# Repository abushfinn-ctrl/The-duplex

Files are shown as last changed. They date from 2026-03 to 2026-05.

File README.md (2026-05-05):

# The-duplex
A wireless split keyboard with 42 keys, made in a 3d printed case. Designed and built for HackClub and improved typing erogonomics. I got a new Macbook lately and my old keyboard was on it's last few breaths, so I decided to make a new keyboard that is also ergonomic. You can use the PCB files to order the PCB from Jlcpcb or your preffered PCB manufacturer. The bill of materials is also provided, look at aliexpress but if the parts are available locally for cheaper then obviously that would work aswell. I printed the case in Clay colour Matte PLA with a layer height of 0.2mm on my Prusa Mk3s+.
# Finished!
I finished the project and i've been waiting to be a little bit more free with school to do this journal. I modified the case because it was going to be too thick with the battery inside so I decided to put the battery on top next to the keys. Everything went pretty smoothly I used some heat inserts and double sided tape for the battery. Overall I like it, it looks cool but I'm not sure I really enjoy typing on it. It's not quite the right positions for the keys and it's just off so I can only get 45WPM vs my normal 110WPM. But i learnt a lot and had fun! I added some leather on the bottom so it grips a little better too.



# The Schematic
The schematic is split into a left and right side with the root sheet having the mousebites.
Here is the left side. 

And here is the right side. Exactly the same.

 We can achieve this by using hierarchical sheets. 
 
To make hierarchical sheeting you can click this button on the side bar or the keyboard button S.
Once setup your heirarchy should look like this.


# The PCB
The PCB is fairly simple. Import a template into kicad to use as a layout tool on where to place the switches. I used ergogen (https://ergogen.xyz/new) to edit a layout and then important that into Kicad as an image to get roughly lined up. Here is my PCB at the very end after routing and drawing my edge cuts.

Don't forget to add some customisation like your name!

# The Case 
I designed the case in Autodesk Fusion, there we're 100% some issues but nothing a bit of time and youtube videos can't fix. I designed the top and then bottom then mirrored and copied them for the other side.


# BOM
| Item | Description | Quantity | Unit Price (CAD$) | Total Price (CAD$) | Unit Price (USD$) | Total Price (USD$) | URL | Running total (CAD$ with tax) | Running total (USD$ with tax) |
| --- | --- | --- | --- | --- | --- | --- | --- | --- | --- |
| 102050 1000mAh LiPO Battery | 20mm\*50mm\*10mm 3.7v Lithium battery. 2Pack | 1 | $12.38 | $12.38 | $8.90 | $8.90 | [Battery](https://www.aliexpress.com/item/1005006394926759.html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) | 12.38$ | 8.90$ |
| Gateron Switches 50 Pack | 50 Gateron Auburn Switches | 1 | $22.71 | $22.71 | $16.33 | $16.33 | [Switches](https://www.aliexpress.com/item/1005006091988869.html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) | 35.09$ | 25.23$ |
| XIAO nRF52840 | XIAO 2 pack microcontroller | 1 | $47.72 | $47.72 | $34.31 | $34.31 | [XIAO](https://www.aliexpress.com/item/1005009937098547.html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) | 82.81$ | 59.54$ |
| Gateron Hotswap Sockets | 70pack of Gateron hotswap sockets | 1 | $22.64 | $22.64 | $16.28 | $16.28 | [Hotswap Sockets](https://www.aliexpress.com/item/1005007267551458.html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) | 105.45$ | 75.81$ |
| PCB | 5 PCB's ordered from JLCPCB | 1 | $58.41 | $58.41 | $41.99 | $41.99 | N/A | 163.86$ | 117.81$ |
| 1N5189 Diodes | 100 pieces | 1 | $3.05 | $3.05 | $2.19 | $2.19 | [DIODE](https://www.aliexpress.com/item/1005004617332808.html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) | 166.91$ | 120.00$ |
| Keycaps | Already have | | | | | | | | |

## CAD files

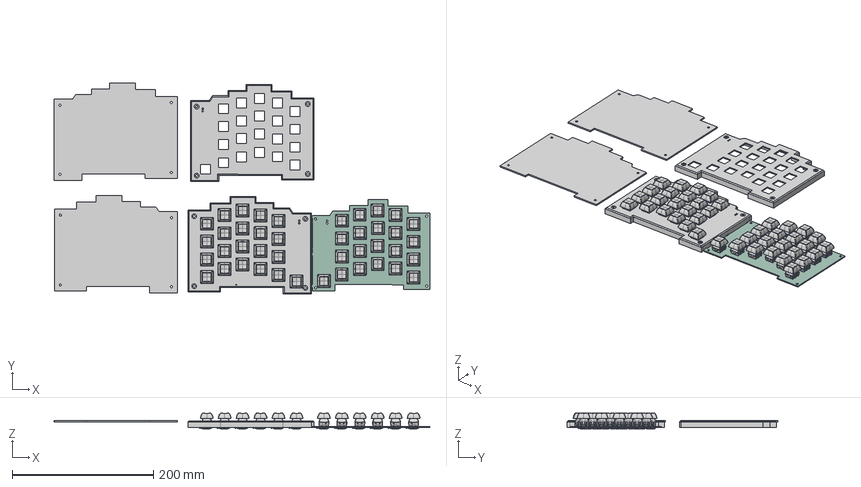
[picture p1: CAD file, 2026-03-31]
CAD/TheDuplex.step
532.1 x 298.5 x 22.0 mm
Contact x 84
DSA_Keycap_CherryMX x 42
splitkbd 1.3.1 x 42
D_SOD-123 x 42
R_0805_2012Metric x 4
splitkbd_PCB

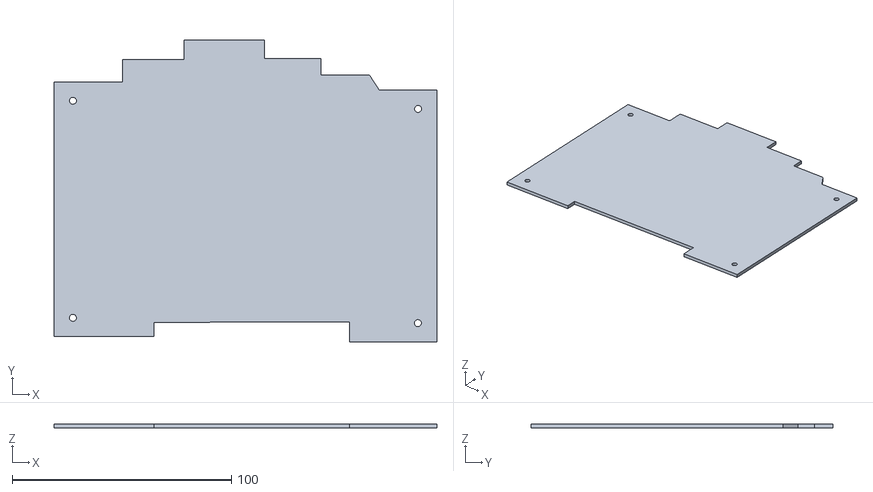
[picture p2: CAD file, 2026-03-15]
CAD/leftbottom.stl
174.6 x 137.7 x 2.00

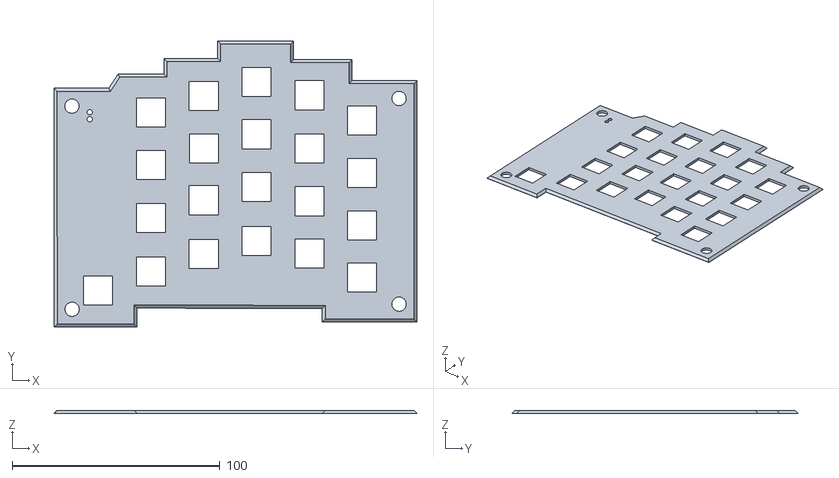
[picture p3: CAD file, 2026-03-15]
CAD/righttop.stl
174.6 x 137.7 x 1.60

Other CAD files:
CAD/rightbottom.stl
CAD/lefttop.stl
CAD/TheDuplex.f3z

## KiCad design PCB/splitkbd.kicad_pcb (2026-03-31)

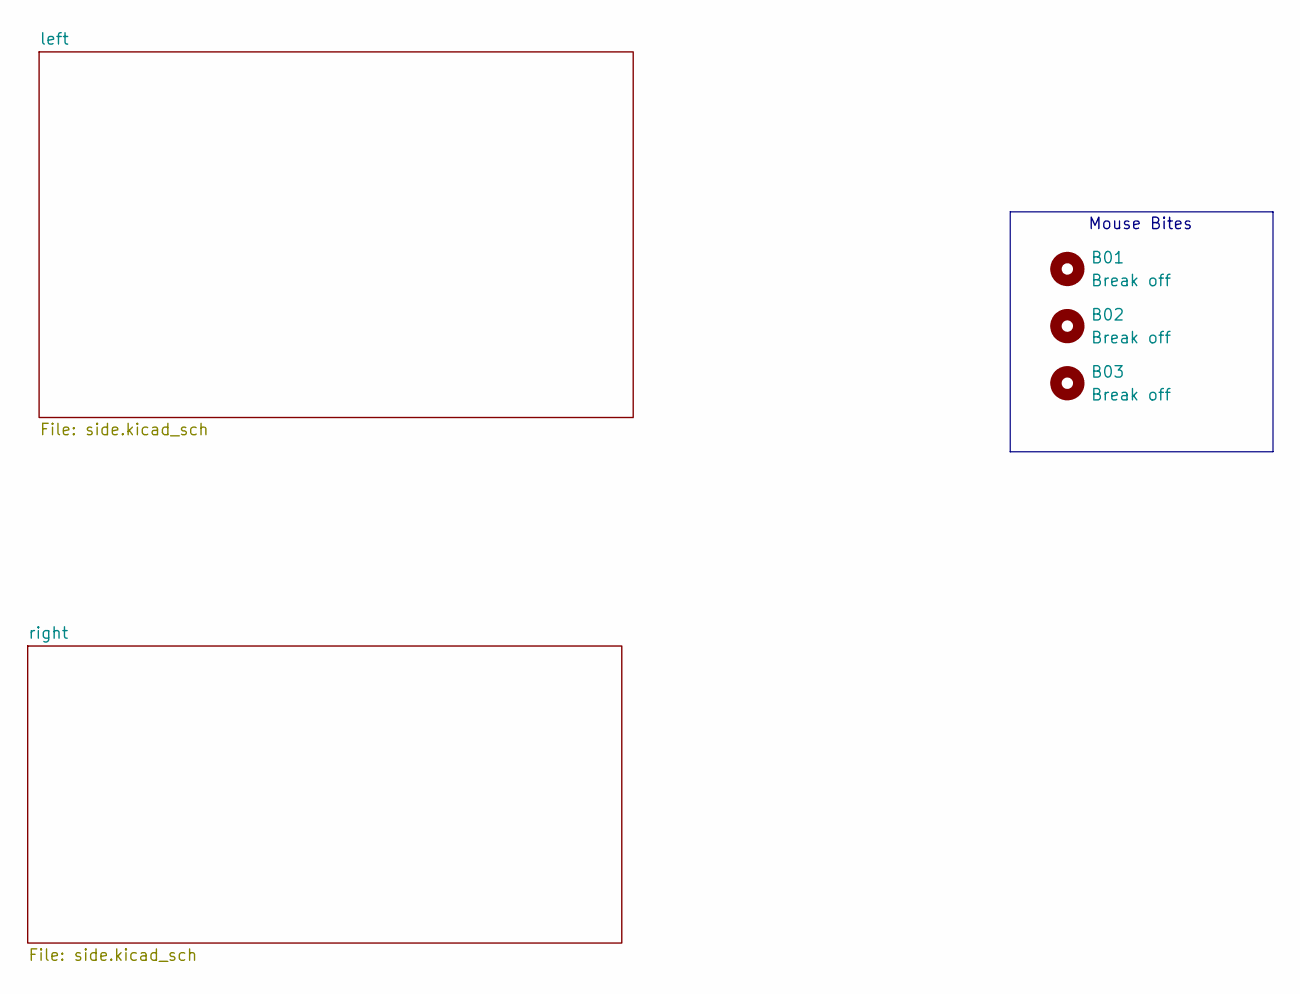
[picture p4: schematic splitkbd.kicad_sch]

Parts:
B01, B02, B03: Break off; mouse-bite-5mm-slot

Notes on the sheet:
Mouse Bites

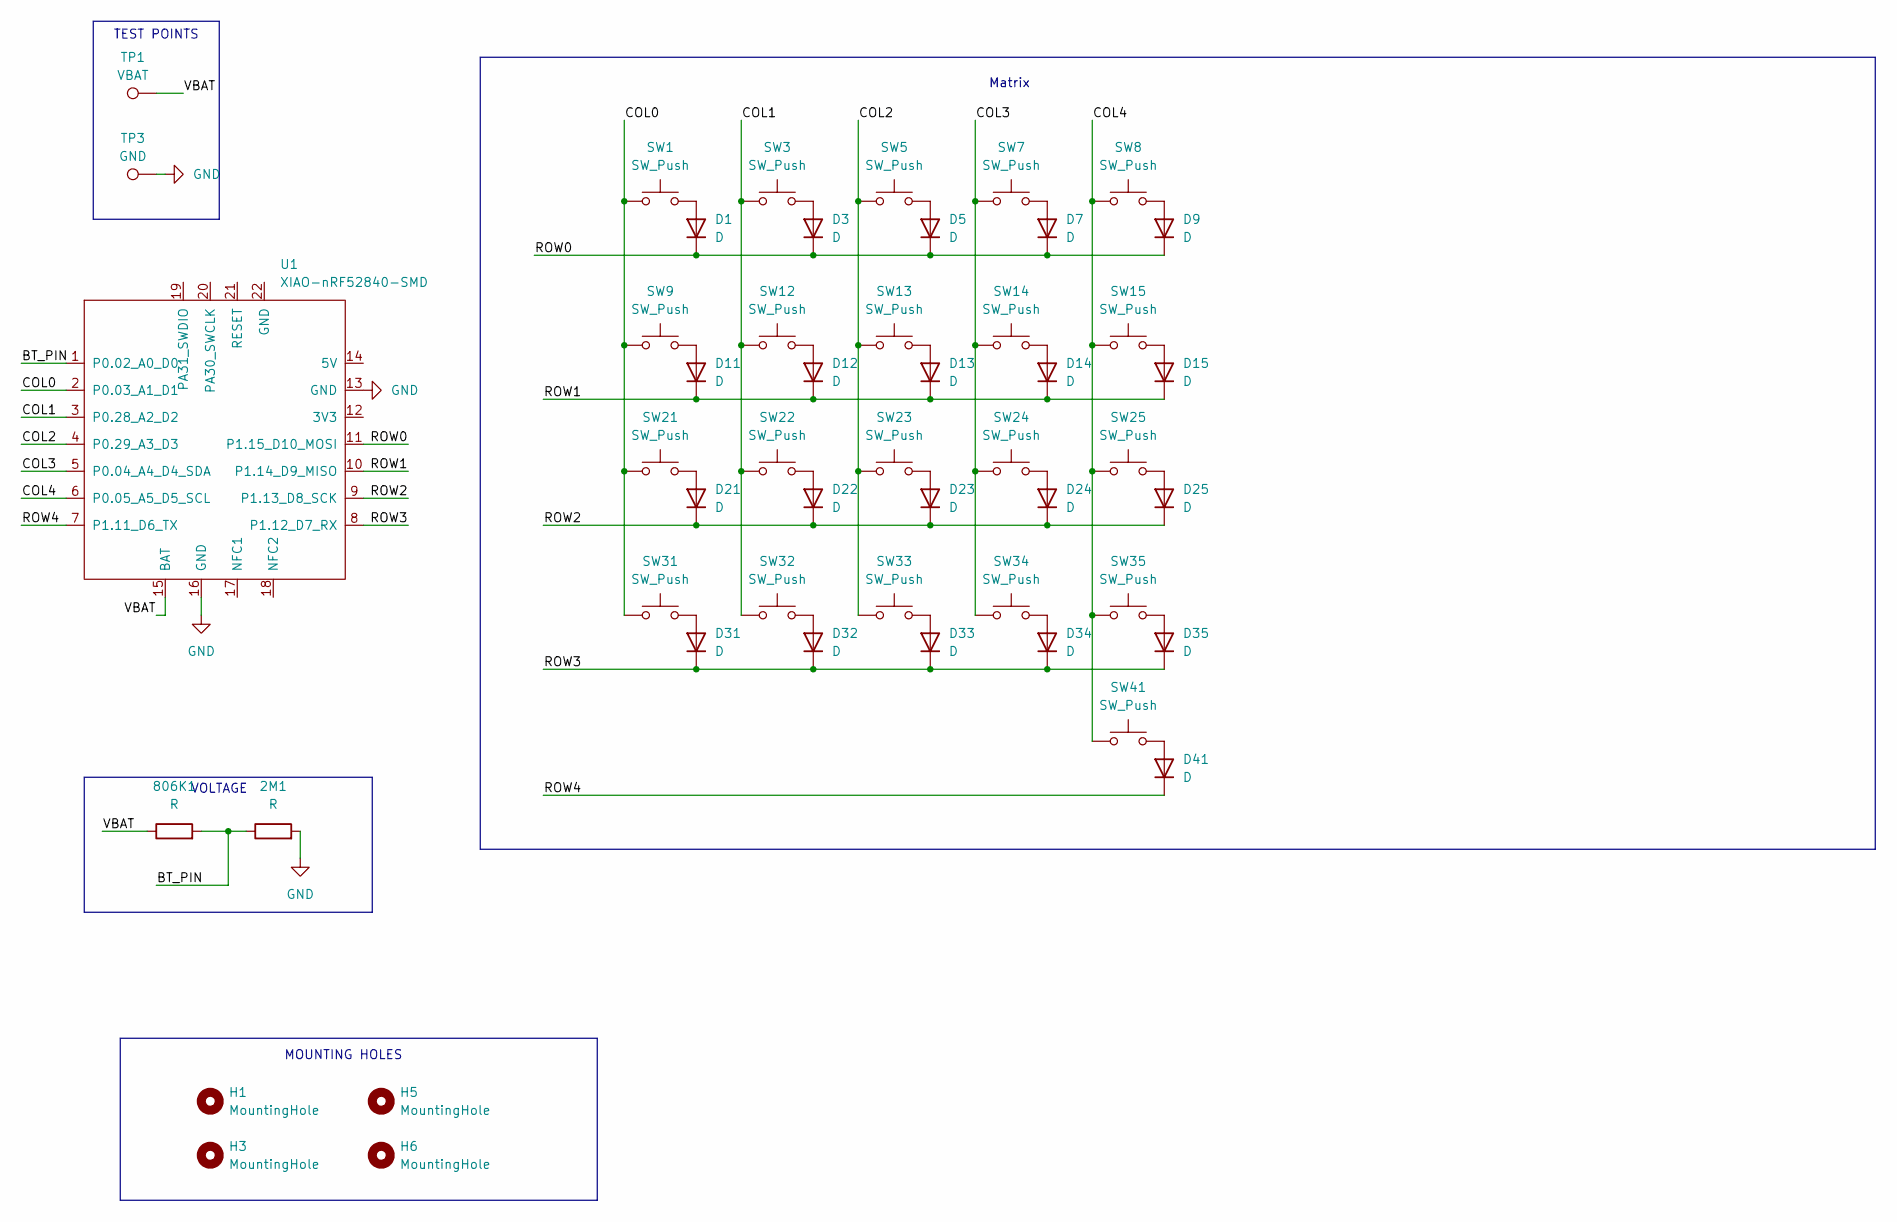
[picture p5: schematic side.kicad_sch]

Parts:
2M1, 806K1: R; R_0805_2012Metric
D1, D3, D5, D7, D9, D11, D12, D13, D14, D15, D21, D22, D23, D24, D25, D31, D32, D33, D34, D35, D41: D; D_SOD-123
H1, H3, H5, H6: MountingHole; MountingHole_3.2mm_M3
SW1, SW3, SW5, SW7, SW8, SW9, SW12, SW13, SW14, SW15, SW21, SW22, SW23, SW24, SW25, SW31, SW32, SW33, SW34, SW35, SW41: SW_Push; SW_MX_HS_CPG151101S11_1.25u
TP1: VBAT; TestPoint_Pad_2.0x2.0mm
TP3: GND; TestPoint_Pad_2.0x2.0mm
U1: XIAO-nRF52840-SMD; modified-XIAO-nRF52840-SMD

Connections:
/left/BT_PIN: 2M1.1, 806K1.2, U1.1 (P0.02_A0_D0)
/left/COL0: SW1.1, SW9.1, SW21.1, SW31.1, U1.2 (P0.03_A1_D1)
/left/COL1: SW3.1, SW12.1, SW22.1, SW32.1, U1.3 (P0.28_A2_D2)
/left/COL2: SW5.1, SW13.1, SW23.1, SW33.1, U1.4 (P0.29_A3_D3)
/left/COL3: SW7.1, SW14.1, SW24.1, SW34.1, U1.5 (P0.04_A4_D4_SDA)
/left/COL4: SW8.1, SW15.1, SW25.1, SW35.1, SW41.1, U1.6 (P0.05_A5_D5_SCL)
/left/ROW0: D1.1 (K), D3.1 (K), D5.1 (K), D7.1 (K), D9.1 (K), U1.11 (P1.15_D10_MOSI)
/left/ROW1: D11.1 (K), D12.1 (K), D13.1 (K), D14.1 (K), D15.1 (K), U1.10 (P1.14_D9_MISO)
/left/ROW2: D21.1 (K), D22.1 (K), D23.1 (K), D24.1 (K), D25.1 (K), U1.9 (P1.13_D8_SCK)
/left/ROW3: D31.1 (K), D32.1 (K), D33.1 (K), D34.1 (K), D35.1 (K), U1.8 (P1.12_D7_RX)
/left/ROW4: D41.1 (K), U1.7 (P1.11_D6_TX)
/left/VBAT: 806K1.1, TP1.1, U1.15 (BAT)
GND: 2M1.2, TP3.1, U1.13 (GND), U1.16 (GND); also elsewhere on the board
unnamed: D1.2 (A), SW1.2
unnamed: D3.2 (A), SW3.2
unnamed: D5.2 (A), SW5.2
unnamed: D7.2 (A), SW7.2
unnamed: D9.2 (A), SW8.2
unnamed: D11.2 (A), SW9.2
unnamed: D12.2 (A), SW12.2
unnamed: D13.2 (A), SW13.2
unnamed: D14.2 (A), SW14.2
unnamed: D15.2 (A), SW15.2
unnamed: D21.2 (A), SW21.2
unnamed: D22.2 (A), SW22.2
unnamed: D23.2 (A), SW23.2
unnamed: D24.2 (A), SW24.2
unnamed: D25.2 (A), SW25.2
unnamed: D31.2 (A), SW31.2
unnamed: D32.2 (A), SW32.2
unnamed: D33.2 (A), SW33.2
unnamed: D34.2 (A), SW34.2
unnamed: D35.2 (A), SW35.2
unnamed: D41.2 (A), SW41.2

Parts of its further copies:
D2, D4, D6, D8, D10, D16, D17, D18, D19, D20, D26, D27, D28, D29, D30, D36, D37, D38, D39, D40, D42: D; D_SOD-123
H2, H4, H7, H8: MountingHole; MountingHole_3.2mm_M3
R2, R4: R; R_0805_2012Metric
SW2, SW4, SW6, SW10, SW11, SW16, SW17, SW18, SW19, SW20, SW26, SW27, SW28, SW29, SW30, SW36, SW37, SW38, SW39, SW40, SW42: SW_Push; SW_MX_HS_CPG151101S11_1.25u
TP2: VBAT; TestPoint_Pad_2.0x2.0mm
TP4: GND; TestPoint_Pad_2.0x2.0mm
U2: XIAO-nRF52840-SMD; modified-XIAO-nRF52840-SMD

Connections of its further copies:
/right/BT_PIN: R2.2, R4.1, U2.1 (P0.02_A0_D0)
/right/COL0: SW2.1, SW16.1, SW26.1, SW36.1, U2.2 (P0.03_A1_D1)
/right/COL1: SW4.1, SW17.1, SW27.1, SW37.1, U2.3 (P0.28_A2_D2)
/right/COL2: SW6.1, SW18.1, SW28.1, SW38.1, U2.4 (P0.29_A3_D3)
/right/COL3: SW10.1, SW19.1, SW29.1, SW39.1, U2.5 (P0.04_A4_D4_SDA)
/right/COL4: SW11.1, SW20.1, SW30.1, SW40.1, SW42.1, U2.6 (P0.05_A5_D5_SCL)
/right/ROW0: D2.1 (K), D4.1 (K), D6.1 (K), D8.1 (K), D10.1 (K), U2.11 (P1.15_D10_MOSI)
/right/ROW1: D16.1 (K), D17.1 (K), D18.1 (K), D19.1 (K), D20.1 (K), U2.10 (P1.14_D9_MISO)
/right/ROW2: D26.1 (K), D27.1 (K), D28.1 (K), D29.1 (K), D30.1 (K), U2.9 (P1.13_D8_SCK)
/right/ROW3: D36.1 (K), D37.1 (K), D38.1 (K), D39.1 (K), D40.1 (K), U2.8 (P1.12_D7_RX)
/right/ROW4: D42.1 (K), U2.7 (P1.11_D6_TX)
/right/VBAT: R2.1, TP2.1, U2.15 (BAT)
GND: R4.2, TP4.1, U2.13 (GND), U2.16 (GND); also elsewhere on the board
unnamed: D2.2 (A), SW2.2
unnamed: D4.2 (A), SW4.2
unnamed: D6.2 (A), SW6.2
unnamed: D8.2 (A), SW10.2
unnamed: D10.2 (A), SW11.2
unnamed: D16.2 (A), SW16.2
unnamed: D17.2 (A), SW17.2
unnamed: D18.2 (A), SW18.2
unnamed: D19.2 (A), SW19.2
unnamed: D20.2 (A), SW20.2
unnamed: D26.2 (A), SW26.2
unnamed: D27.2 (A), SW27.2
unnamed: D28.2 (A), SW28.2
unnamed: D29.2 (A), SW29.2
unnamed: D30.2 (A), SW30.2
unnamed: D36.2 (A), SW36.2
unnamed: D37.2 (A), SW37.2
unnamed: D38.2 (A), SW38.2
unnamed: D39.2 (A), SW39.2
unnamed: D40.2 (A), SW40.2
unnamed: D42.2 (A), SW42.2

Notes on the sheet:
VOLTAGE
MOUNTING HOLES
TEST POINTS
Matrix

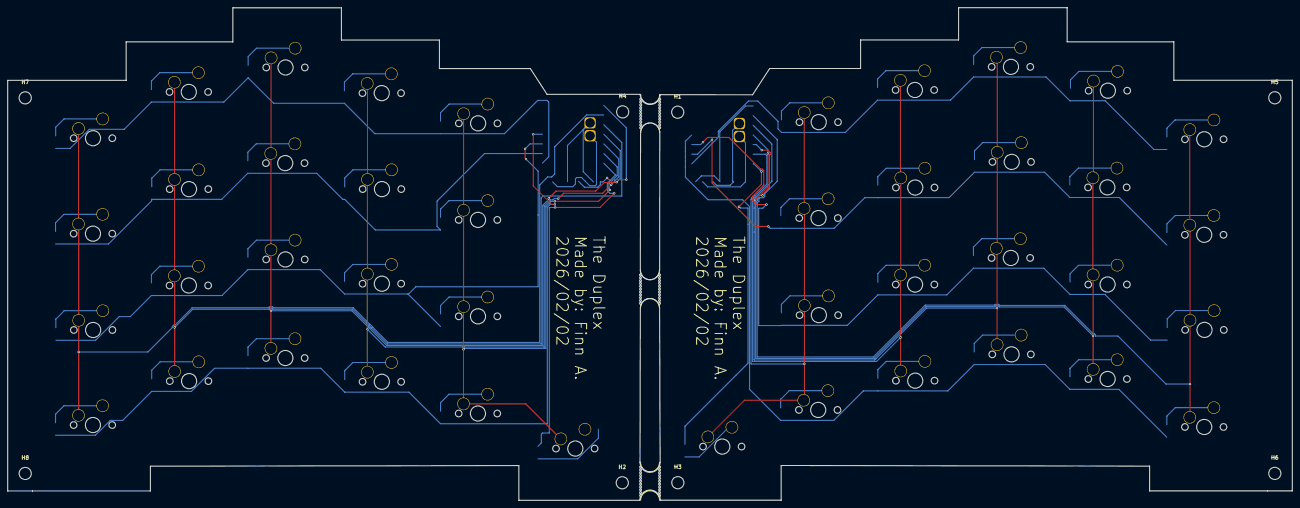
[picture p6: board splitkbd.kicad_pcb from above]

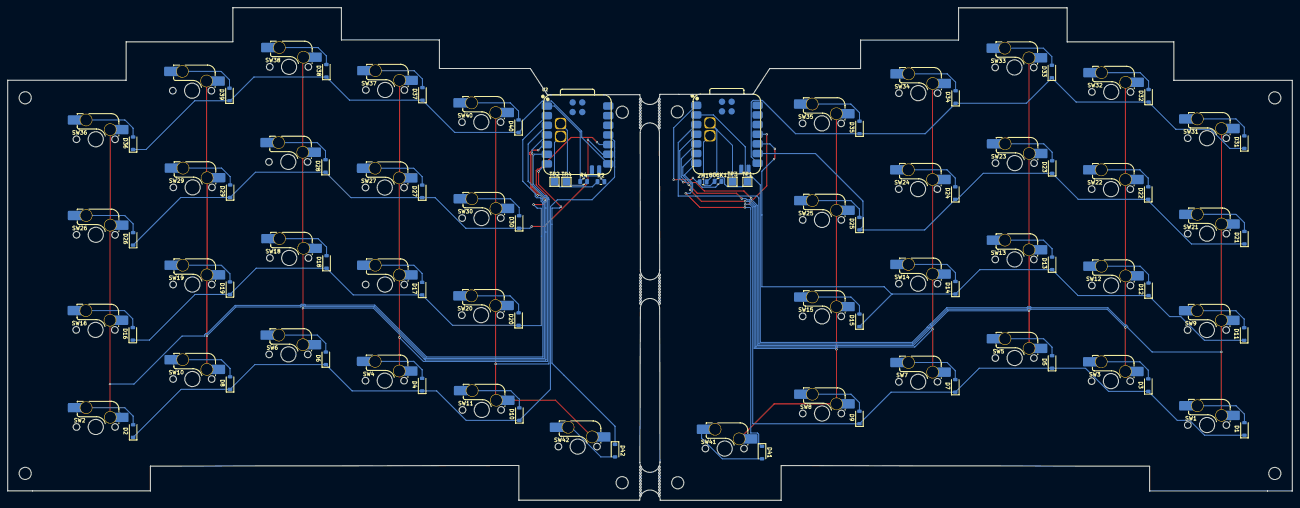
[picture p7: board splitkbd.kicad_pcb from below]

Board: 2 copper layers, 338.3 x 129.7 mm, 105 parts (94 on the bottom side), 67 nets.
